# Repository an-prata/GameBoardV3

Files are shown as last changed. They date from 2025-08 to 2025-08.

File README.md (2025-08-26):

# GameBoardV3
A half sized, 3D printed, and hand-wired keyboard for playing games. The keyboard uses an Adafruit SAMD21 QT Py board.

## Required Parts
All model files can be found in the `Models` directory, the SolidWorks files (`.SLDPRT` and `.SLDASM`) are not necessary unless you wish to make modifications to the models. All models are designed as to not require any support (tested on a Bambu A1 printer). When slicing the models you will need to reorrient them in your slicer, the Bambu Studio slicer's automatic orientation function finds the correct orientation for all these models if you intend to print them on a Bambu.

These parts will need to be 3D printed:
* `Base Plate.STL`
* `Switch Plate.STL`
* `Fastener.STL` (18x)

And you will also need these:
* Choice of mechanical keyboard switch (28x)
* Choice of 1U keycaps (28x)
  * The [OLKB Preonic Acute Keycaps](https://drop.com/buy/drop-olkb-preonic-acute-keycaps) are super cheap and fairly good quality, and are what I've used for my build.
* Wire
  * I'd recommend solid core wire for connecting switches to eachother in columns and rows, and stranded wire for connecting those columns and rows to the controller.
* Adafruit SAMD21 QT Py
  * I'm sure you could use any number of other controllers, this is just the one I've used and tested. You will however need at least 11 digital pins.
* Diode (28x)
  * Recourses I've found tend to recommend a [1N4148 diode](https://www.digikey.com/en/products/detail/onsemi/1N4148/458603). I'm fairly sure a number of diodes would work, and you can also find the 1N4148 diode on Amazon if DigiKey isn't your deal. Its advisable to get more than just 28 in case of mistakes.

Optionally you may print one or both of these to give your keyboard a ten degree tilt:
* `Angled Holder.STL`
  * Single large part. I like to do this in a different color to the plate files.
* `Angled Plate.STL` + `Angled Plate Peg.STL` (14x)

> NOTE: For the `Fastener.STL` file and `Angled Plate Peg.STL` I recommend printing a few spare, prints for these guys fail pretty easily and they can be damaged when trying to install. I've done 20 and 16 respectively and thats been plenty.

> Assembly segment coming soon.

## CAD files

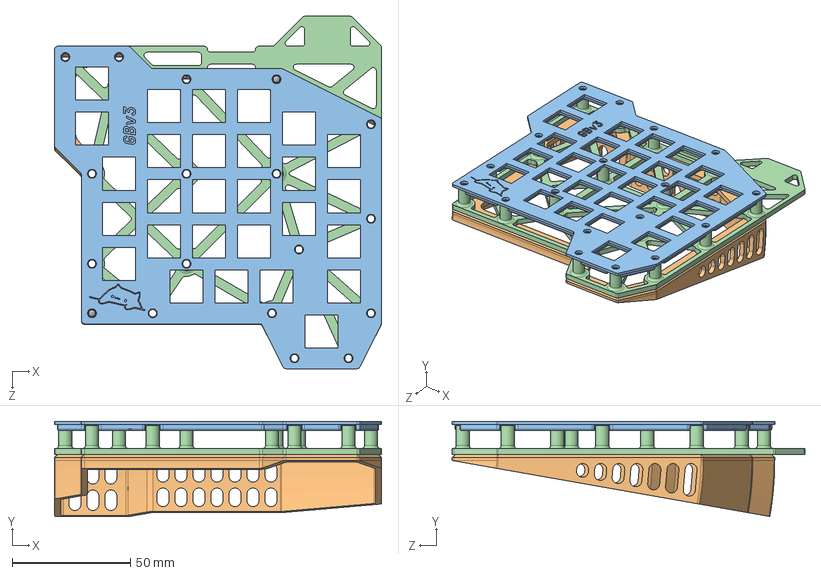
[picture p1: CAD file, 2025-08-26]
Models/Gameboard with Angled Plate.SLDASM
138.4 x 40.2 x 149.2 mm
Base Plate
Switch Plate
Angled Plate
Angled Plate Peg x 2

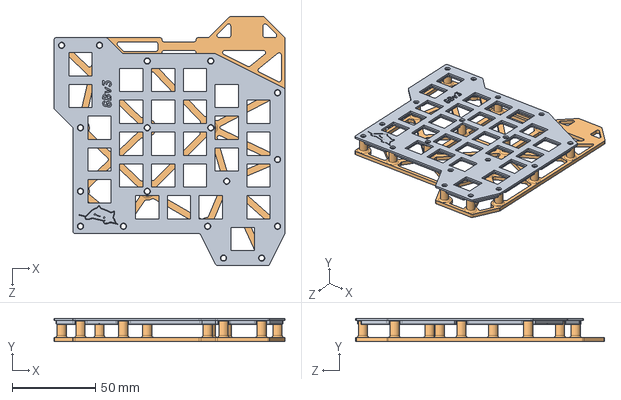
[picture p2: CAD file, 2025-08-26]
Models/Gameboard.SLDASM
138.4 x 14.0 x 149.2 mm
Base Plate
Switch Plate

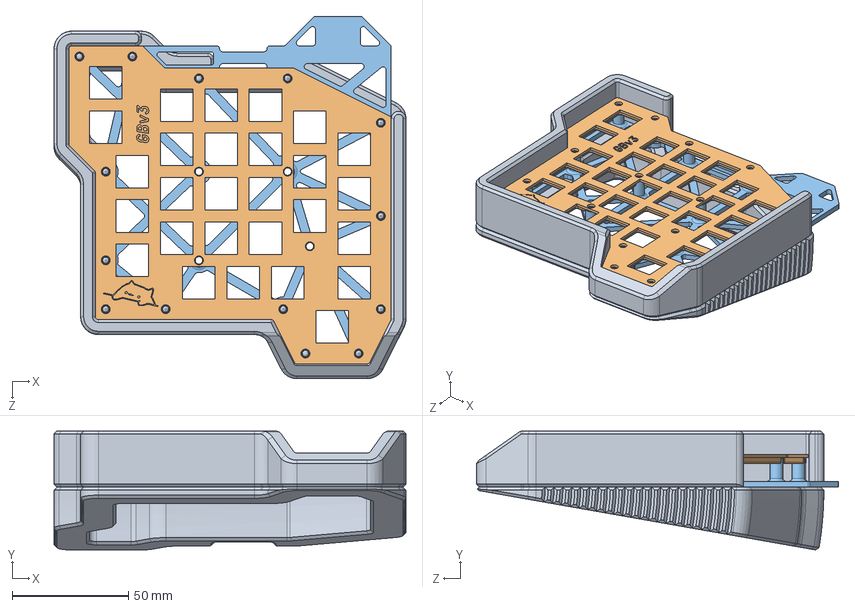
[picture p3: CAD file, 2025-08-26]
Models/Gameboard with Angled Holder.SLDASM
151.1 x 51.1 x 155.6 mm
Base Plate
Switch Plate
Angled Holder

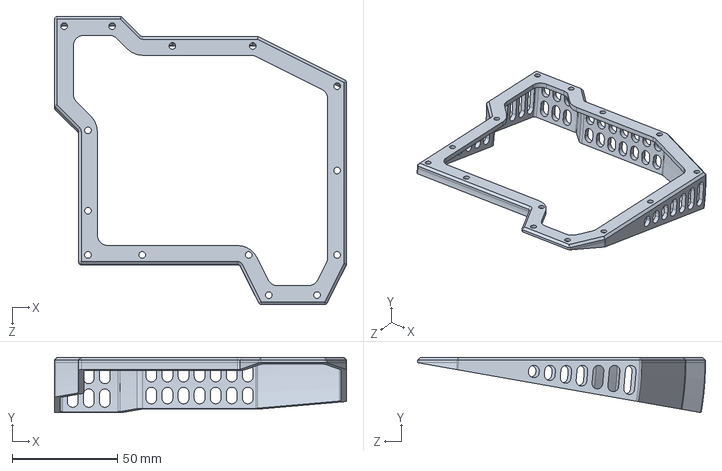
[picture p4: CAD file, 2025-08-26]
Models/Angled Plate.SLDPRT
138.4 x 26.2 x 136.5 mm

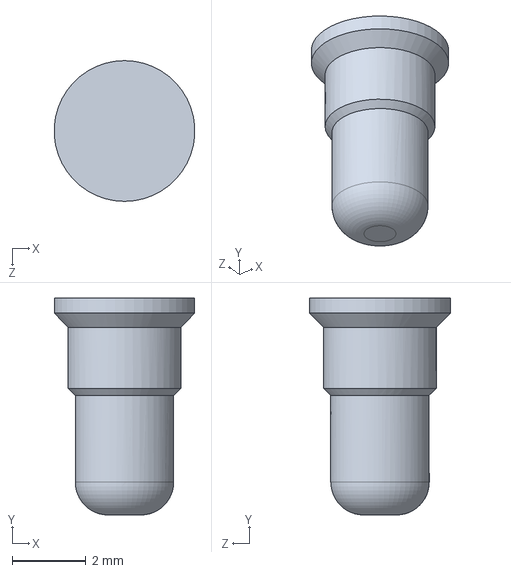
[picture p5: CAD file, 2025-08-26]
Models/Angled Plate Peg.SLDPRT
3.80 x 5.87 x 3.81 mm

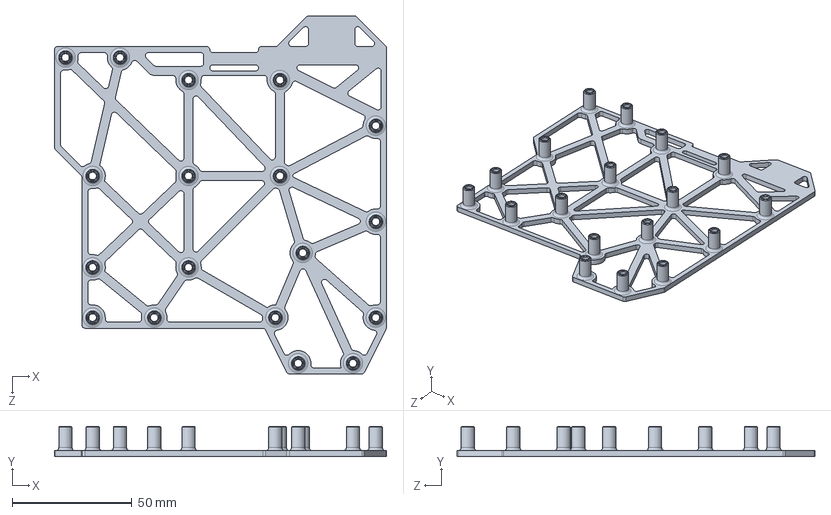
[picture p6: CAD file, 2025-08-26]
Models/Base Plate.SLDPRT
138.4 x 12.7 x 149.2 mm

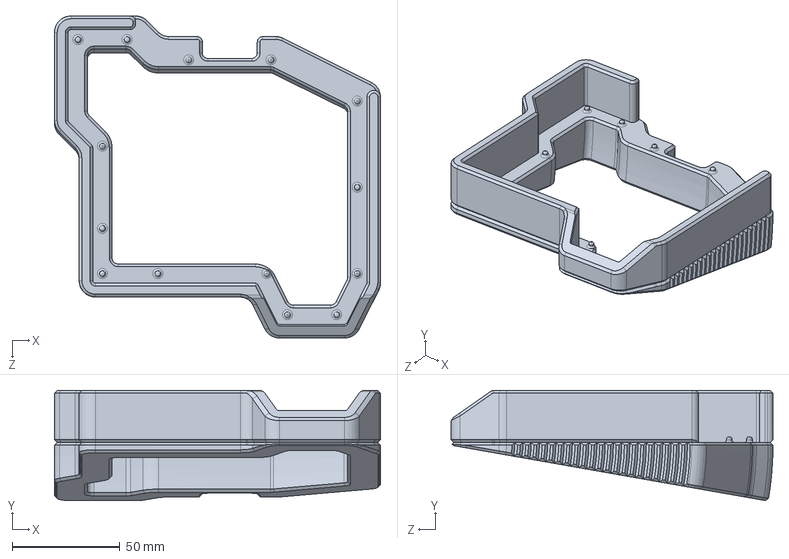
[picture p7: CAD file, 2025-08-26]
Models/Angled Holder.SLDPRT
151.1 x 51.1 x 149.2 mm

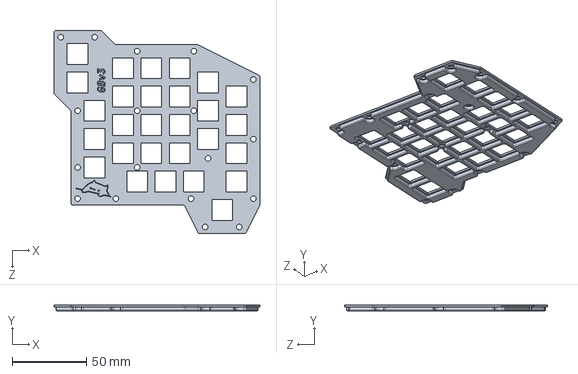
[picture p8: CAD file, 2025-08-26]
Models/Switch Plate.SLDPRT
138.4 x 3.81 x 136.5 mm

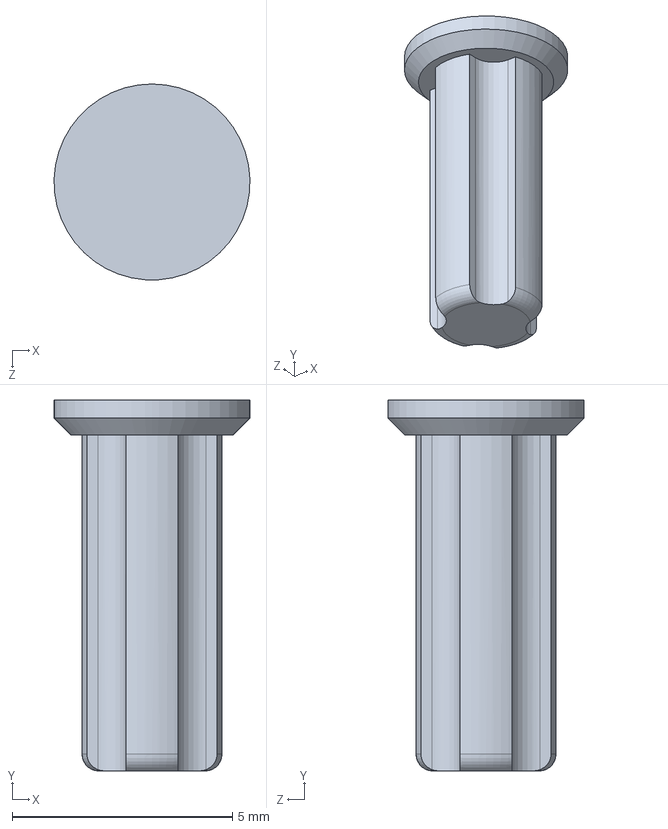
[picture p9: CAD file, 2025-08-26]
Models/Fastener.SLDPRT
4.44 x 8.41 x 4.45 mm

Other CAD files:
Models/Angled Plate Peg.STL
Models/Angled Plate.STL
Models/Base Plate.STL
Models/Fastener.STL
Models/Switch Plate.STL

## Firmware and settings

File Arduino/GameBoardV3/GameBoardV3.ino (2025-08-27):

#include <Keyboard.h>
#include <Adafruit_NeoPixel.h>

#define NUM_COLUMNS 6
#define NUM_ROWS 5
#define NUM_DEBOUNCE_SCANS 4
#define ___ '\0'

#define LED_PIN 11
#define LED_BRIGHTNESS 64
#define LED_CYCLE_STEPS 16
#define LED_CYCLE_TIME_MICROS 1000000 / LED_CYCLE_STEPS
#define PERCENT_COLOR_PER_MICRO 0.000001


// Matrix pins.

const uint8_t PIN_COLUMNS[NUM_COLUMNS] = { 10, 9, 8, 7, 6, 5 };
const uint8_t PIN_ROWS[NUM_ROWS] = { 0, 1, 2, 3, 4 };
uint32_t PIN_DESC_COLUMNS[NUM_COLUMNS];
uint32_t PIN_DESC_ROWS[NUM_ROWS];


/**
 * RGBW color components (which need to be reversed for some fucking reason) as struct fields for
 * manipulation of individual channels.
 */
typedef struct {
    uint8_t b;
    uint8_t g;
    uint8_t r;
    uint8_t w;
} ColorComponents;


/**
 * A union between a packed 32 bit color and a struct with its components. Bit-wise these are
 * equivilant and therefor no tag is required and both formats may be accessed with no prerequisits.
 */
typedef union {
    ColorComponents components;
    uint32_t packed_color;
} Color;


/**
 * Layers available on the keeb.
 */
typedef enum {
    LAYER_BASE = 0xFC,
    LAYER_FN
} Layer;


// Keymaps, in a more intuitive layout. Later they will be rearranged into a format optomized for
// scanning and reading quickly.

const char _KEYMAP[NUM_ROWS][NUM_COLUMNS] = {
    KEY_ESC,         '1',       '2',           '3',  '4',   '5',
    KEY_TAB,         'q',       'w',           'e',  'r',   't',
    'v',             'a',       's',           'd',  'f',   'g',
    KEY_LEFT_SHIFT,  'z',       'x',           'c',  ___,   'b',
    KEY_LEFT_CTRL,   LAYER_FN,  KEY_LEFT_ALT,  ' ',  ___,   '.'
};

const char _KEYMAP_FN[NUM_ROWS][NUM_COLUMNS] = {
    '`',   KEY_F1,  KEY_F2,  KEY_F3,       KEY_F4,  KEY_F5,
    ___,   ___,     ___,     ___,          ___,     ___,
    ___,   ___,     ___,     ___,          ___,     ___,
    ___,   ___,     ___,     ___,          ___,     ___,
    ___,   ___,     ___,     KEY_RETURN,   ___,     ___
};


// Keymaps with the axes flipped, so that the columns can be scanned in the outer loop and rows in
// the inner loop. This reduces cache misses in the scanning function and simply requires that 
// reading the state arrays is done column-row rather than row-column.

char KEYMAP[NUM_COLUMNS][NUM_ROWS];
char KEYMAP_FN[NUM_COLUMNS][NUM_ROWS];


// Colors for LED light.

/*
const Color COLOR_IDLE = Color {
    // Yellow
    .components = ColorComponents {
        .w = 0,
        .r = 128,
        .g = 96,
        .b = 0,
    }
};

const Color COLOR_ACTIVE = Color {
    // Red
    .components = ColorComponents{
        .w = 0,
        .r = 255,
        .g = 0,
        .b = 0,
    }
};
*/

const Color COLOR_IDLE = Color {
    // Cyan
    .components = ColorComponents {
        .b = 255,
        .g = 192,
        .r = 0,
        .w = 0,
    }
};

const Color COLOR_ACTIVE = Color {
    // Purple
    .components = ColorComponents{
        .b = 255,
        .g = 0,
        .r = 255,
        .w = 0,
    }
};


/**
 * Pre-computed colors for activity decay.
 */
uint32_t COLOR_CYCLE[LED_CYCLE_STEPS];


// Keyboard state.

bool key_scans[NUM_DEBOUNCE_SCANS][NUM_COLUMNS][NUM_ROWS] = { false };
uint8_t current_scan = NUM_DEBOUNCE_SCANS - 1;

Layer current_layer = LAYER_BASE;

uint8_t fn_key_pos_row;
uint8_t fn_key_pos_column;
unsigned long scan_time = 0;
unsigned long scan_printout_timestamp = 0;


// LED state.

uint32_t led_cycle_step = 0;
unsigned long prev_time = 0;
bool show_pending = false;

Adafruit_NeoPixel neopixel(1, LED_PIN, NEO_GRB + NEO_KHZ800);


/**
 * Update the `key_scans` and `current_layer` variables with the current keyboard state. This
 * functions performs a scan of the key matrix.
 */
static void update_keys() {
    current_layer = LAYER_BASE;
    current_scan = (current_scan + 1) % NUM_DEBOUNCE_SCANS;

    for (uint8_t column = 0; column < NUM_COLUMNS; column++) {
        uint32_t column_pin = PIN_DESC_COLUMNS[column];
        uint32_t column_mask = 1ul << column_pin;

        // Configure as output and clear pin.

        PORT->Group[PORTA].PINCFG[column_pin].reg = (uint8_t)(PORT_PINCFG_INEN | PORT_PINCFG_DRVSTR);
        PORT->Group[PORTA].DIRSET.reg = column_mask;
        PORT->Group[PORTA].OUTCLR.reg = column_mask;

        // The QT Py SAMD21 is a 48 MHz controller.
        //
        // 48 MHz = (48 * 1000 * 1000) Hz => 48^-1 μs per clock cycle.
        //
        // Each no-op should therefor take approx. 0.02 microseconds. Below is 25 such no-ops,
        // without which holding the top row of the keyboard tends to get false presses on, as if
        // there if some physical delay between clearing/setting a pin and seeing the effect.
        //
        // Its pretty fucking jank but it seems to work pretty damn well. In total its about a 0.521
        // microsecond delay.

        __asm__ __volatile__ ("nop");
        __asm__ __volatile__ ("nop");
        __asm__ __volatile__ ("nop");
        __asm__ __volatile__ ("nop");
        __asm__ __volatile__ ("nop");

        __asm__ __volatile__ ("nop");
        __asm__ __volatile__ ("nop");
        __asm__ __volatile__ ("nop");
        __asm__ __volatile__ ("nop");
        __asm__ __volatile__ ("nop");

        __asm__ __volatile__ ("nop");
        __asm__ __volatile__ ("nop");
        __asm__ __volatile__ ("nop");
        __asm__ __volatile__ ("nop");
        __asm__ __volatile__ ("nop");

        __asm__ __volatile__ ("nop");
        __asm__ __volatile__ ("nop");
        __asm__ __volatile__ ("nop");
        __asm__ __volatile__ ("nop");
        __asm__ __volatile__ ("nop");

        __asm__ __volatile__ ("nop");
        __asm__ __volatile__ ("nop");
        __asm__ __volatile__ ("nop");
        __asm__ __volatile__ ("nop");
        __asm__ __volatile__ ("nop");

        for (uint8_t row = 0; row < NUM_ROWS; row++) {
            uint32_t row_pin = PIN_DESC_ROWS[row];
            uint32_t row_mask = 1ul << row_pin;

            key_scans[current_scan][column][row] = (PORT->Group[PORTA].IN.reg & row_mask) == 0;
        }

        // For whatever reason this nearly eliminates false positives with successive key presses
        // within the same row. It probably grounds it or something.
        //
        // Configures pin an input and sets high.

        PORT->Group[PORTA].PINCFG[column_pin].reg = (uint8_t)(PORT_PINCFG_INEN);
        PORT->Group[PORTA].DIRCLR.reg = column_mask;
        PORT->Group[PORTA].OUTSET.reg = column_mask;
    }

    if (key_scans[current_scan][fn_key_pos_column][fn_key_pos_row]) {
        key_scans[current_scan][fn_key_pos_column][fn_key_pos_row] = false;
        current_layer = LAYER_FN;
    }

    unsigned long current_time = micros();
    
    if (current_time - scan_printout_timestamp >= 1000 * 250) {
        scan_printout_timestamp = current_time;
        unsigned long scan_duration = current_time - scan_time;
        unsigned long scan_rate = (1000 * 1000) / scan_duration;
        Serial.printf("Scan Time: %lu μs\tScan Rate: %lu hz\n", scan_duration, scan_rate);
    }

    scan_time = current_time;
}


/**
 * Returns `true` if the key at the given position was pressed in the last scan.
 */
static inline bool key_pressed(uint8_t column, uint8_t row) {
    for (uint8_t i = 1; i < NUM_DEBOUNCE_SCANS / 2 + 1; i++) {
        uint8_t scan_idx = (current_scan + i) % NUM_DEBOUNCE_SCANS;
        
        if (key_scans[scan_idx][column][row]) {
            return false;
        }
    }
    
    for (uint8_t i = NUM_DEBOUNCE_SCANS / 2 + 1; i < NUM_DEBOUNCE_SCANS; i++) {
        uint8_t scan_idx = (current_scan + i) % NUM_DEBOUNCE_SCANS;
        
        if (!key_scans[scan_idx][column][row]) {
            return false;
        }
    }

    return true;
}


/**
 * Returns `true` if the key at the given position was released in the last scan.
 */
static inline bool key_released(uint8_t column, uint8_t row) {
    for (uint8_t i = 1; i < NUM_DEBOUNCE_SCANS / 2 + 1; i++) {
        uint8_t scan_idx = (current_scan + i) % NUM_DEBOUNCE_SCANS;
        
        if (!key_scans[scan_idx][column][row]) {
            return false;
        }
    }
    
    for (uint8_t i = NUM_DEBOUNCE_SCANS / 2 + 1; i < NUM_DEBOUNCE_SCANS; i++) {
        uint8_t scan_idx = (current_scan + i) % NUM_DEBOUNCE_SCANS;
        
        if (key_scans[scan_idx][column][row]) {
            return false;
        }
    }

    return true;
}


/**
 * Scale all components/color channels by the given scalar.
 */
static inline ColorComponents scale_components(ColorComponents components, double scale) {
    return ColorComponents {
        .b = (uint8_t)((double)components.b * scale),
        .g = (uint8_t)((double)components.g * scale),
        .r = (uint8_t)((double)components.r * scale),
        .w = (uint8_t)((double)components.w * scale),
    };
}


/**
 * Add the corrosponding components of `lhs` and `rhs` and return the result.
 */
static inline ColorComponents add_components(ColorComponents lhs, ColorComponents rhs) {
    return ColorComponents {
        .b = (uint8_t)(lhs.b + rhs.b),
        .g = (uint8_t)(lhs.g + rhs.g),
        .r = (uint8_t)(lhs.r + rhs.r),
        .w = (uint8_t)(lhs.w + rhs.w),
    };
}


void setup() {
    noInterrupts();

    for (uint8_t row = 0; row < NUM_ROWS; row++) {
        PIN_DESC_ROWS[row] = g_APinDescription[PIN_ROWS[row]].ulPin;

        uint32_t pin = PIN_DESC_ROWS[row];
        uint32_t mask = 1ul << pin;

        // Configure as input with pullup resistor.

        PORT->Group[PORTA].PINCFG[pin].reg = (uint8_t)(PORT_PINCFG_INEN | PORT_PINCFG_PULLEN);
        PORT->Group[PORTA].DIRCLR.reg = mask;

        // Set the "default" state of the pin.

        PORT->Group[PORTA].OUTSET.reg = mask;
    }

    for (uint8_t column = 0; column < NUM_COLUMNS; column++) {
        PIN_DESC_COLUMNS[column] = g_APinDescription[PIN_COLUMNS[column]].ulPin;

        uint32_t pin = PIN_DESC_COLUMNS[column];
        uint32_t mask = 1ul << pin;

        // Set pin to output mode and enable reading.

        PORT->Group[PORTA].PINCFG[pin].reg = (uint8_t)(PORT_PINCFG_INEN | PORT_PINCFG_DRVSTR);
        PORT->Group[PORTA].DIRSET.reg = mask;

        // Set pin.

        PORT->Group[PORTA].OUTSET.reg = mask;
    }

    // Flip the axes of the keymaps to reduce cache misses while scanning the matrix.

    for (uint8_t row = 0; row < NUM_ROWS; row++) {
        for (uint8_t column = 0; column < NUM_COLUMNS; column++) {
            KEYMAP[column][row] = _KEYMAP[row][column];
            KEYMAP_FN[column][row] = _KEYMAP_FN[row][column];
        }
    }

    // Find the FN key ahead of time, so that layer checks may be performed in a single check,
    // rather than checking each key while scanning the matrix.

    for (uint8_t column = 0; column < NUM_COLUMNS; column++) {
        for (uint8_t row = 0; row < NUM_ROWS; row++) {
            if (KEYMAP[column][row] == LAYER_FN) {
                fn_key_pos_row = row;
                fn_key_pos_column = column;
                goto found_fn;
            }
        }
    }

found_fn:

    Keyboard.begin();

    neopixel.begin();
    neopixel.setBrightness(LED_BRIGHTNESS);
    neopixel.fill(neopixel.gamma32(COLOR_IDLE.packed_color));
    neopixel.show();

    // Precompute LED light animations to avoid performing the computation and blocking further
    // matrix scans.
    
    for (uint8_t cycle_step = 0; cycle_step < LED_CYCLE_STEPS; cycle_step++) {
        double percent = (double)cycle_step / (double)LED_CYCLE_STEPS;

        Color current_color = Color {
            .components = add_components(
                scale_components(COLOR_IDLE.components, percent),
                scale_components(COLOR_ACTIVE.components, (1.0 - percent))
            )
        };

        COLOR_CYCLE[cycle_step] = neopixel.gamma32(current_color.packed_color);
    }

    Serial.begin(9600);
}


void loop() {
loop_start:
    update_keys();

    if (current_layer == LAYER_BASE) {
        for (uint8_t column = 0; column < NUM_COLUMNS; column++) {
            for (uint8_t row = 0; row < NUM_ROWS; row++) {
                char key = KEYMAP[column][row];

                if (key == ___) {
                    continue;
                }

                if (key_released(column, row)) {
                    Keyboard.release(key);
                } else if (key_pressed(column, row)) {
                    Keyboard.press(key);
                    led_cycle_step = 0;
                }
            }
        }
    } else if (current_layer == LAYER_FN) {
        for (uint8_t column = 0; column < NUM_COLUMNS; column++) {
            for (uint8_t row = 0; row < NUM_ROWS; row++) {
                char key = KEYMAP_FN[column][row];

                if (key == ___ && (key = KEYMAP[column][row]) == ___) {
                    continue;
                }

                if (key_released(column, row)) {
                    Keyboard.release(key);
                } else if (key_pressed(column, row)) {
                    Keyboard.press(key);
                    led_cycle_step = 0;
                }
            }
        }
    }

    // If we are at the end of an animation just skip the checks involved with animating the LED.

    if (led_cycle_step == LED_CYCLE_STEPS) {
        goto loop_start;
    }

    // Update LED light based on activity. The else-if deal delays the `show()` call until
    // `canShow()` is more likely to be `true`. It also seperates some computation between scan
    // frames, reducing inconsistency in frame times.

    if (micros() - prev_time >= LED_CYCLE_TIME_MICROS) {
        neopixel.setPixelColor(0, COLOR_CYCLE[led_cycle_step]);
        prev_time = micros();
        led_cycle_step++;
        show_pending = true;
    } else if (show_pending && neopixel.canShow()) {
        neopixel.show();
        show_pending = false;
    }
}
